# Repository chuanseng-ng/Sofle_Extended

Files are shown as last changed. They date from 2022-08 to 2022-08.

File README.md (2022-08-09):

# Sofle_Extended
 Sofle Split Keyboard Design but with extra row & column added

## Details
- Added extra row and column to each side of Sofle split keyboard for more flexibility
- Micro-controller used will have to be Elite-C due to extra ports needed for row and column

## Version history
- V1.0: Initial fabricated PCB with tested functions
- V1.1: Modified PCB component placement to improve aesthetics and feasibility

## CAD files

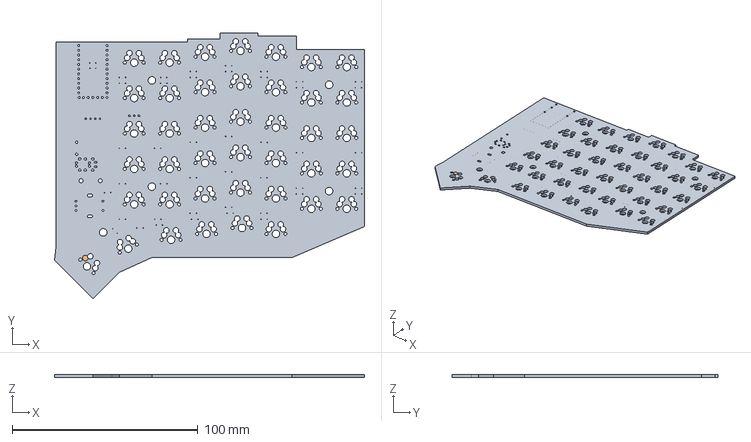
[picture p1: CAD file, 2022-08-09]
Outputs/Sofle_Extended.step
166.7 x 142.9 x 1.60 mm

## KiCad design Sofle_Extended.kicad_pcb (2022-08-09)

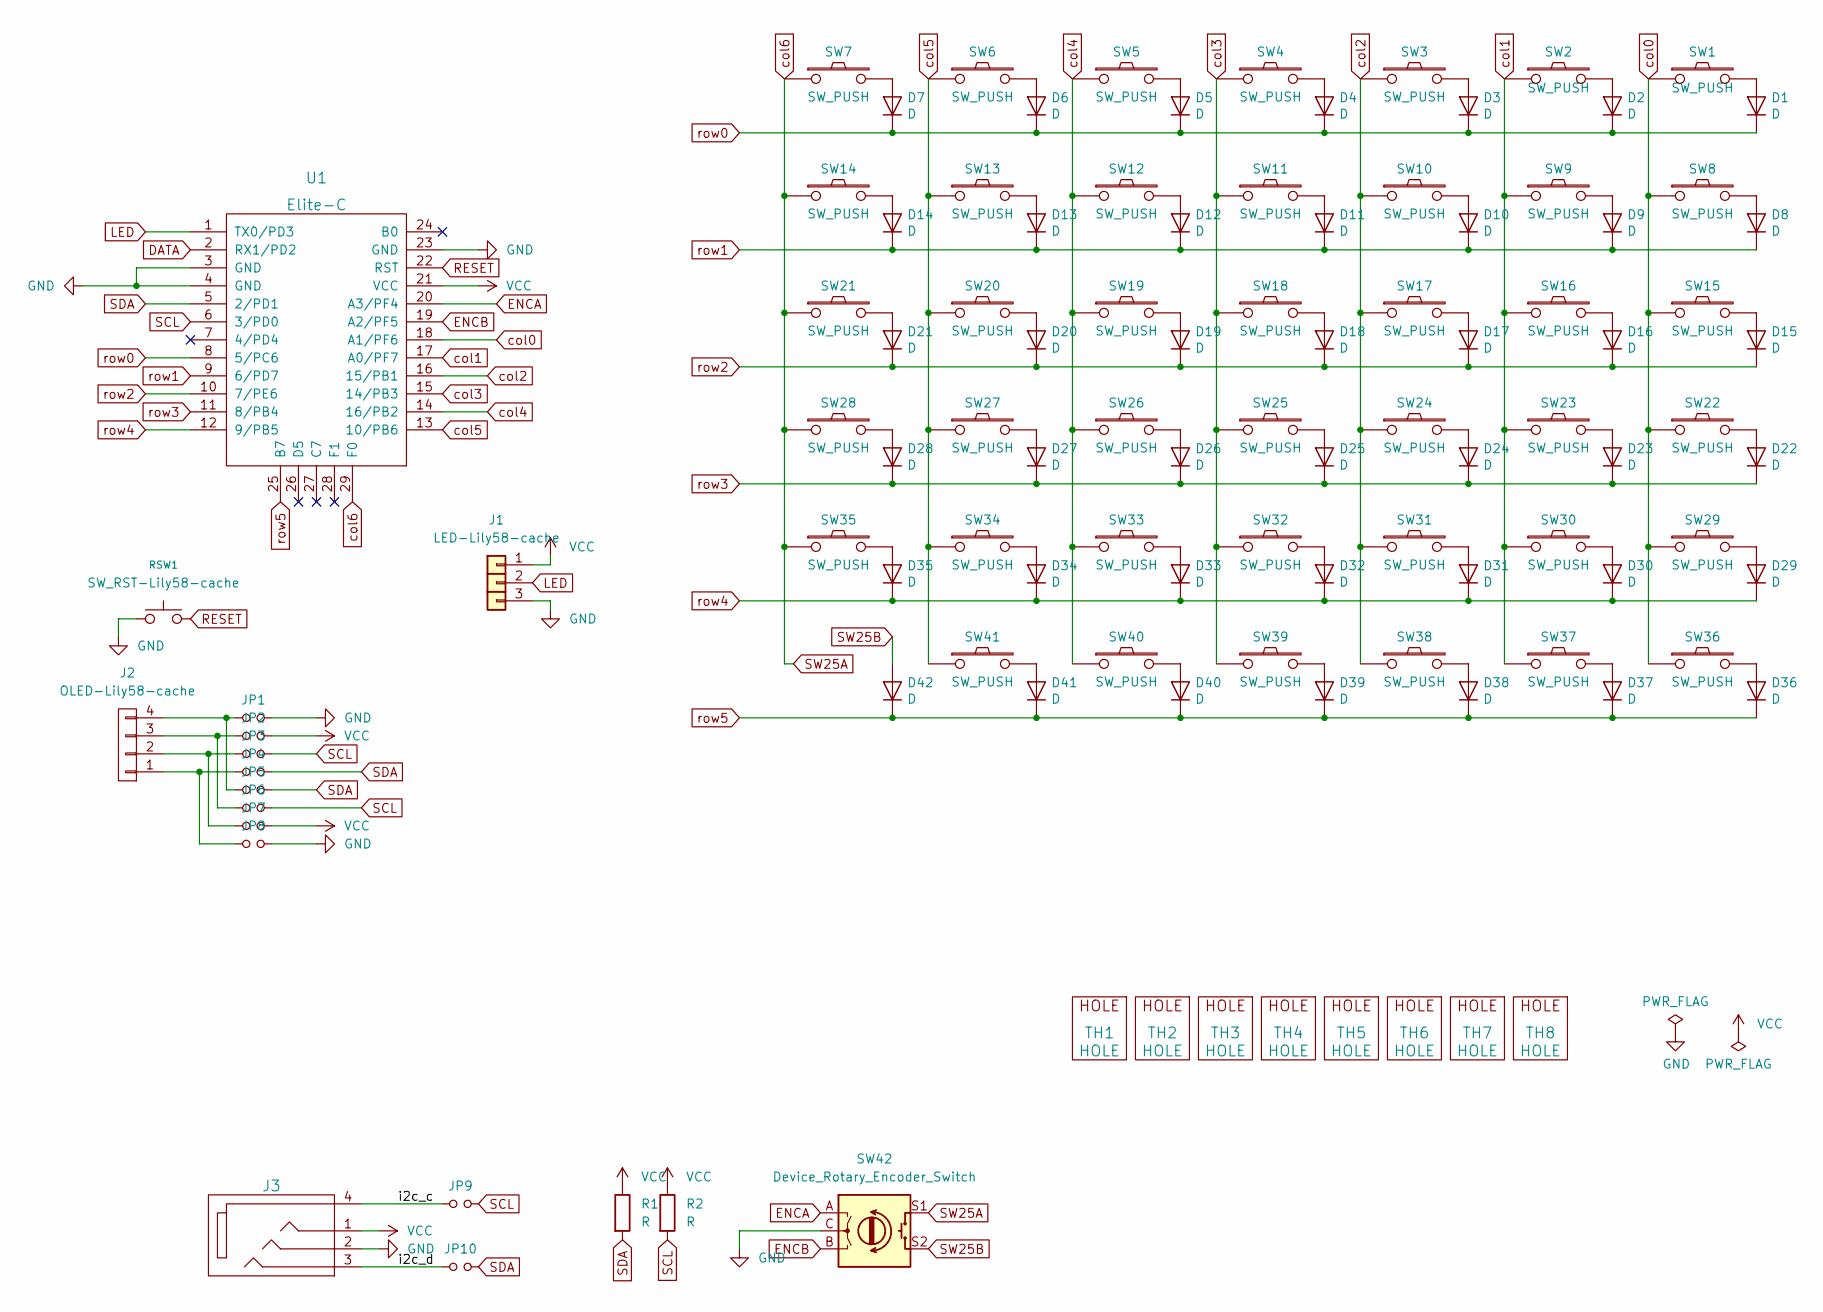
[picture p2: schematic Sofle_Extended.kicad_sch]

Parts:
D1, D2, D3, D4, D5, D6, D7, D8, D9, D10, D11, D12, D13, D14, D15, D16, D17, D18, D19, D20, D21, D22, D23, D24, D25, D26, D27, D28, D29, D30, D31, D32, D33, D34, D35, D36, D37, D38, D39, D40, D41, D42: D; Diode_SOD123
J1: LED-Lily58-cache; LED
J2: OLED-Lily58-cache; OLED_4Pin
J3: SofleKeyboard-rescue_MJ-4PP-9-Lily58-cache-Lily58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; MJ-4PP-9
JP1, JP2, JP3, JP4, JP5, JP6, JP7, JP8, JP9, JP10: Device_Jumper_NO_Small; Jumper
R1, R2: R; R_1206_DoubleSided
RSW1: SW_RST-Lily58-cache; TACT_SWITCH_TVBP06
SW1, SW2, SW3, SW4, SW5, SW6, SW7, SW8, SW9, SW10, SW11, SW12, SW13, SW14, SW15, SW16, SW17, SW18, SW19, SW20, SW21, SW22, SW23, SW24, SW25, SW26, SW27, SW28, SW29, SW30, SW31, SW32, SW33, SW34, SW35, SW36, SW37, SW38, SW39, SW40: SW_PUSH; CherryMX_Hotswap
SW41: SW_PUSH; CherryMX_Hotswap_1.5
SW42: Device_Rotary_Encoder_Switch; RotaryEncoder_Alps_EC11E-Switch_Vertical_H20mm-keebio_modif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
TH1, TH2: HOLE; M2_HOLE_PCB
TH3, TH4, TH5, TH6, TH7, TH8: HOLE; HOLE_M2_TH
U1: Elite-C

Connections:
/i2c_c: J3.4, JP9.1
/i2c_d: J3.3, JP10.1
DATA: U1.2 (RX1/PD2)
ENCA: SW42.A, U1.20 (A3/PF4)
ENCB: SW42.B, U1.19 (A2/PF5)
GND: J1.3, J3.2, JP1.2, JP8.2, RSW1.1, SW42.C, U1.3 (GND), U1.4 (GND), U1.23 (GND)
LED: J1.2, U1.1 (TX0/PD3)
unnamed: D1.2 (A), SW1.2
unnamed: D2.2 (A), SW2.2
unnamed: D3.2 (A), SW3.2
unnamed: D4.2 (A), SW4.2
unnamed: D5.2 (A), SW5.2
unnamed: D6.2 (A), SW6.2
unnamed: D7.2 (A), SW7.2
unnamed: D8.2 (A), SW8.2
unnamed: D9.2 (A), SW9.2
unnamed: D10.2 (A), SW10.2
unnamed: D11.2 (A), SW11.2
unnamed: D12.2 (A), SW12.2
unnamed: D13.2 (A), SW13.2
unnamed: D14.2 (A), SW14.2
unnamed: D15.2 (A), SW15.2
unnamed: D16.2 (A), SW16.2
unnamed: D17.2 (A), SW17.2
unnamed: D18.2 (A), SW18.2
unnamed: D19.2 (A), SW19.2
unnamed: D20.2 (A), SW20.2
unnamed: D21.2 (A), SW21.2
unnamed: D22.2 (A), SW22.2
unnamed: D23.2 (A), SW23.2
unnamed: D24.2 (A), SW24.2
unnamed: D25.2 (A), SW25.2
unnamed: D26.2 (A), SW26.2
unnamed: D27.2 (A), SW27.2
unnamed: D28.2 (A), SW28.2
unnamed: D29.2 (A), SW29.2
unnamed: D30.2 (A), SW30.2
unnamed: D31.2 (A), SW31.2
unnamed: D32.2 (A), SW32.2
unnamed: D33.2 (A), SW33.2
unnamed: D34.2 (A), SW34.2
unnamed: D35.2 (A), SW35.2
unnamed: D36.2 (A), SW36.2
unnamed: D37.2 (A), SW37.2
unnamed: D38.2 (A), SW38.2
unnamed: D39.2 (A), SW39.2
unnamed: D40.2 (A), SW40.2
unnamed: D41.2 (A), SW41.2
unnamed: J2.1, JP4.1, JP8.1
unnamed: J2.2, JP3.1, JP7.1
unnamed: J2.3, JP2.1, JP6.1
unnamed: J2.4, JP1.1, JP5.1
RESET: RSW1.2, U1.22 (RST)
SCL: JP3.2, JP6.2, JP9.2, R2.2, U1.6 (3/PD0)
SDA: JP4.2, JP5.2, JP10.2, R1.2, U1.5 (2/PD1)
SW25A: SW7.1, SW14.1, SW21.1, SW28.1, SW35.1, SW42.S1, U1.29 (F0)
SW25B: D42.2 (A), SW42.S2
VCC: J1.1, J3.1, JP2.2, JP7.2, R1.1, R2.1, U1.21 (VCC)
col0: SW1.1, SW8.1, SW15.1, SW22.1, SW29.1, SW36.1, U1.18 (A1/PF6)
col1: SW2.1, SW9.1, SW16.1, SW23.1, SW30.1, SW37.1, U1.17 (A0/PF7)
col2: SW3.1, SW10.1, SW17.1, SW24.1, SW31.1, SW38.1, U1.16 (15/PB1)
col3: SW4.1, SW11.1, SW18.1, SW25.1, SW32.1, SW39.1, U1.15 (14/PB3)
col4: SW5.1, SW12.1, SW19.1, SW26.1, SW33.1, SW40.1, U1.14 (16/PB2)
col5: SW6.1, SW13.1, SW20.1, SW27.1, SW34.1, SW41.1, U1.13 (10/PB6)
row0: D1.1 (K), D2.1 (K), D3.1 (K), D4.1 (K), D5.1 (K), D6.1 (K), D7.1 (K), U1.8 (5/PC6)
row1: D8.1 (K), D9.1 (K), D10.1 (K), D11.1 (K), D12.1 (K), D13.1 (K), D14.1 (K), U1.9 (6/PD7)
row2: D15.1 (K), D16.1 (K), D17.1 (K), D18.1 (K), D19.1 (K), D20.1 (K), D21.1 (K), U1.10 (7/PE6)
row3: D22.1 (K), D23.1 (K), D24.1 (K), D25.1 (K), D26.1 (K), D27.1 (K), D28.1 (K), U1.11 (8/PB4)
row4: D29.1 (K), D30.1 (K), D31.1 (K), D32.1 (K), D33.1 (K), D34.1 (K), D35.1 (K), U1.12 (9/PB5)
row5: D36.1 (K), D37.1 (K), D38.1 (K), D39.1 (K), D40.1 (K), D41.1 (K), D42.1 (K), U1.25 (B7)

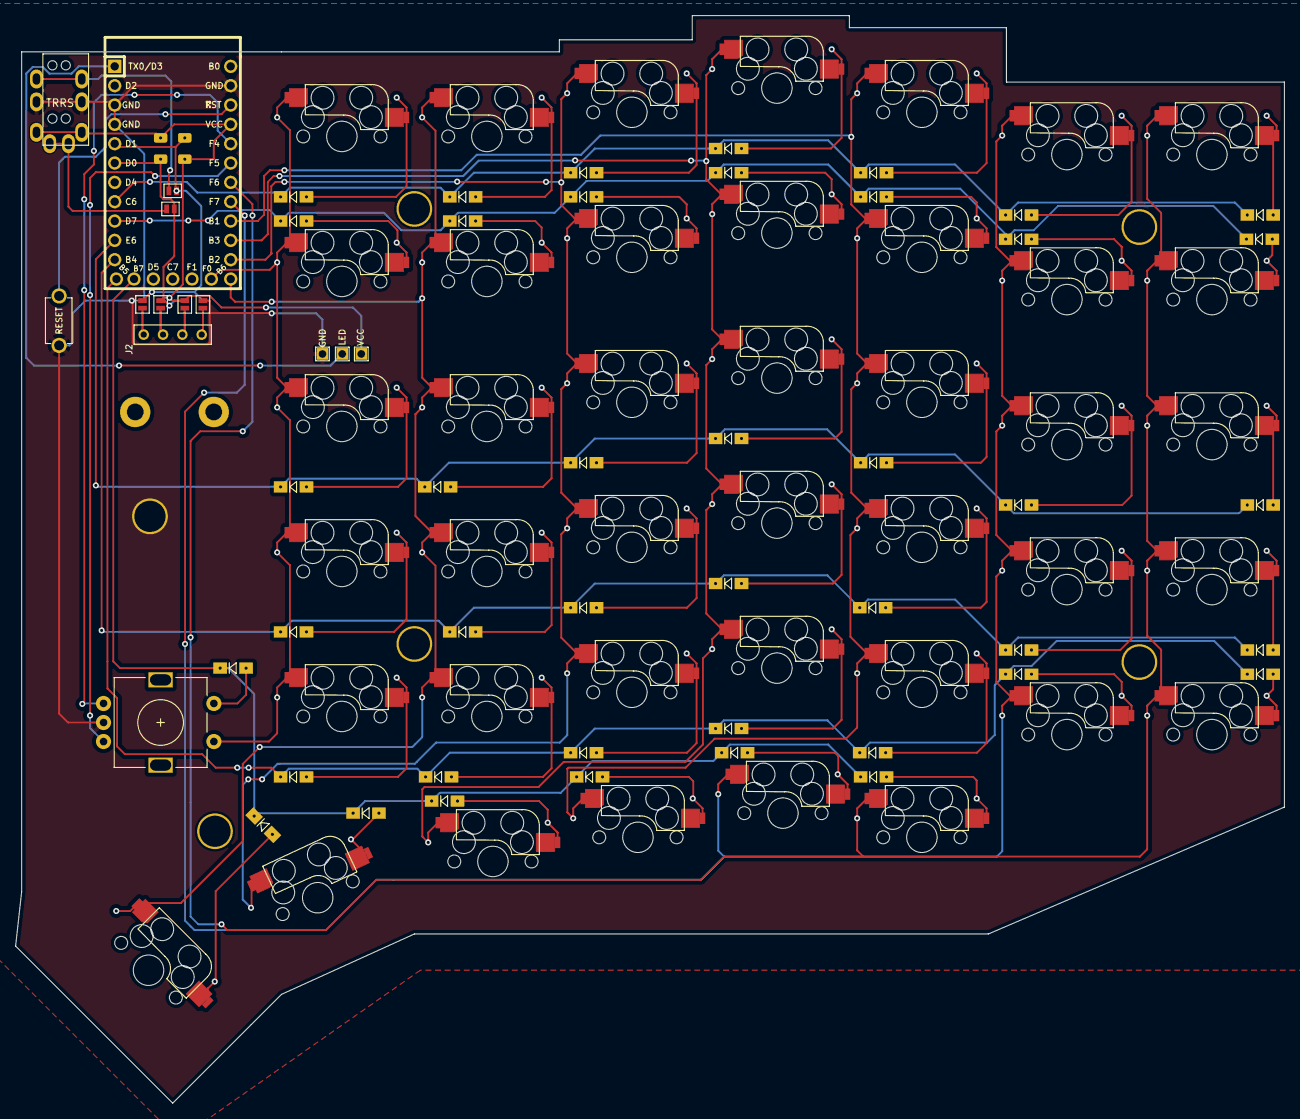
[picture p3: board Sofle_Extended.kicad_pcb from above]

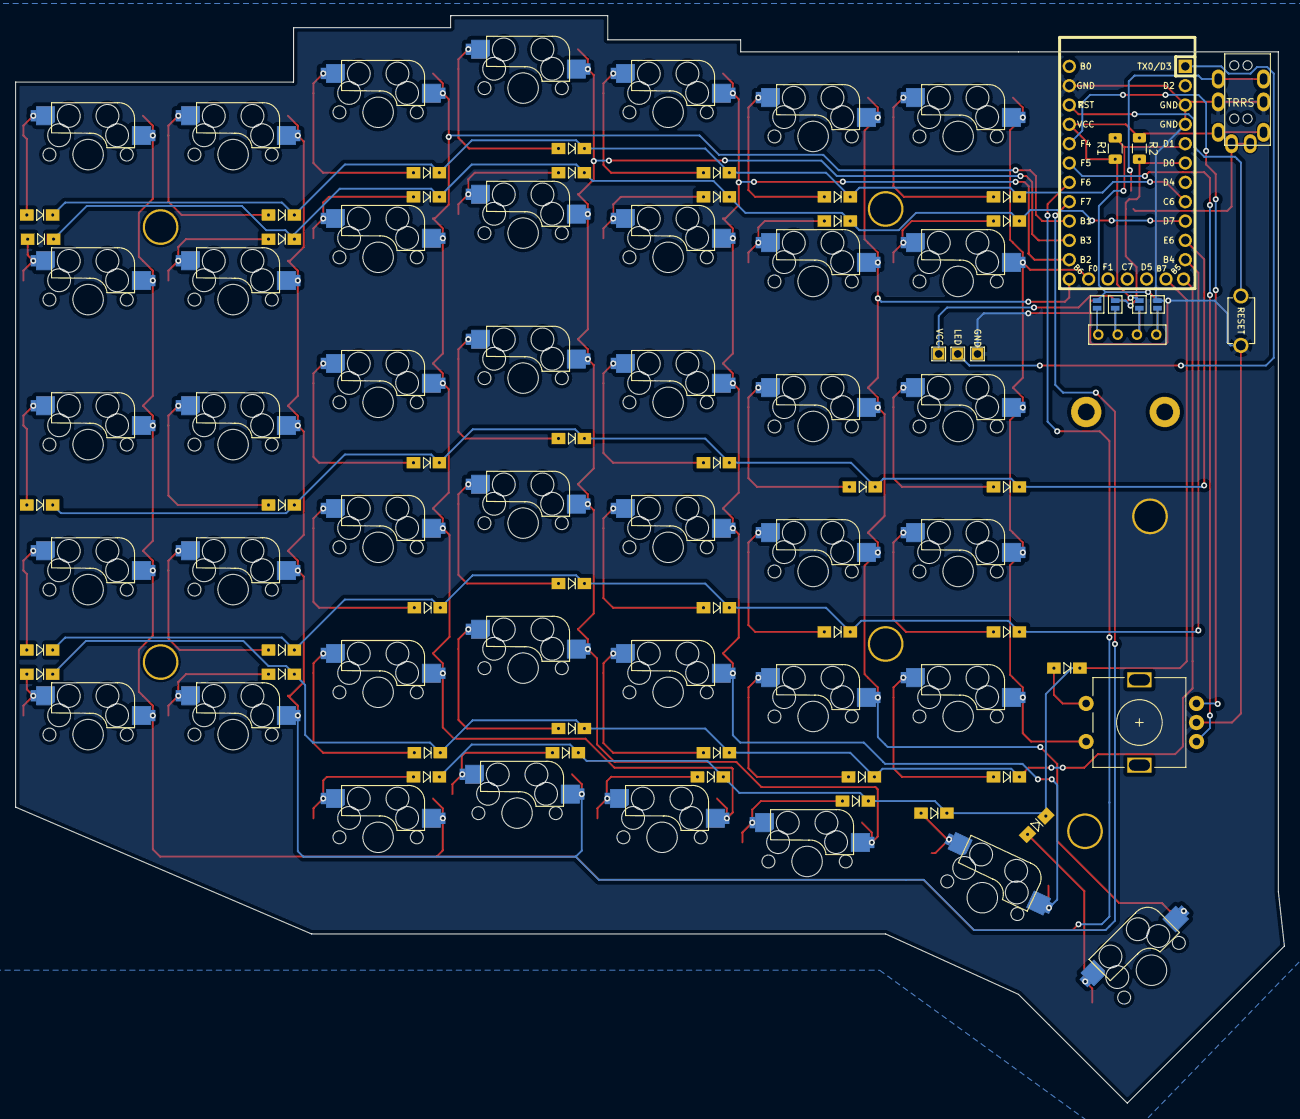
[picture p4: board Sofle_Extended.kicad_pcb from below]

Board: 2 copper layers, 166.7 x 142.9 mm, 109 parts (6 on the bottom side), 69 nets.

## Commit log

2022-08-09 Initial commit for V1.0 design files
    [Sofle_Extended-B_Cu.gbr, Sofle_Extended-B_Mask.gbr, Sofle_Extended-B_Paste.gbr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]
2022-08-09 Add V1.1 design files
    [Sofle_Extended.kicad_pcb, Sofle_Extended.kicad_sch]
